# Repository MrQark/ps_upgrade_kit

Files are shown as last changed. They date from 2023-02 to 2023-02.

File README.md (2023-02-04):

# Power Supply Upgrade Kit

Power Supply Upgrade Kit (PSUK) allows to turn a power supply into LiFePO4 charger

# Objectives

To convert the existing power supply [ATABA S-360-12](https://prom.ua/ua/p1276775685-impulsnyj-blok-pitaniya.html) into LiFePO4 battery charger.

# Requirements

1. Current regulation.

REQ-001. PSUK shall linearly regulate output current up to the Threshold Value.

REQ-002. Current regulation Threshold Value selection shall be done by the variable resistor in the range from 5A to 25A (wider range is also acceptable).

REQ-003. Switching to current regulation shall be indicated by the yellow LED.

REQ-004. Current regulation shall not decrease output voltage lower than 10V to preserve the Fan operation in the current regulation mode.

2. Battery isolation.

REQ-005. If no AC power available the PSUK output shall be electically disconnected from the battery to avoid battery disharge by the fan and voltage feedback stages.

3. Voltage regulation.

REQ-006. PSUK shall extend the output voltage adjustment range up to 15V. Note: in the original state it is limited to 14-14.1V.

4. Fan control.

REQ-007. PSUK shall not activate the cooling FAN if the output current is near zero (0-0.3A) otherwise the FAN shall be operating.

Note: this requirement is for supporting the UPS use case when the soundless operation is preferred.

# Concept

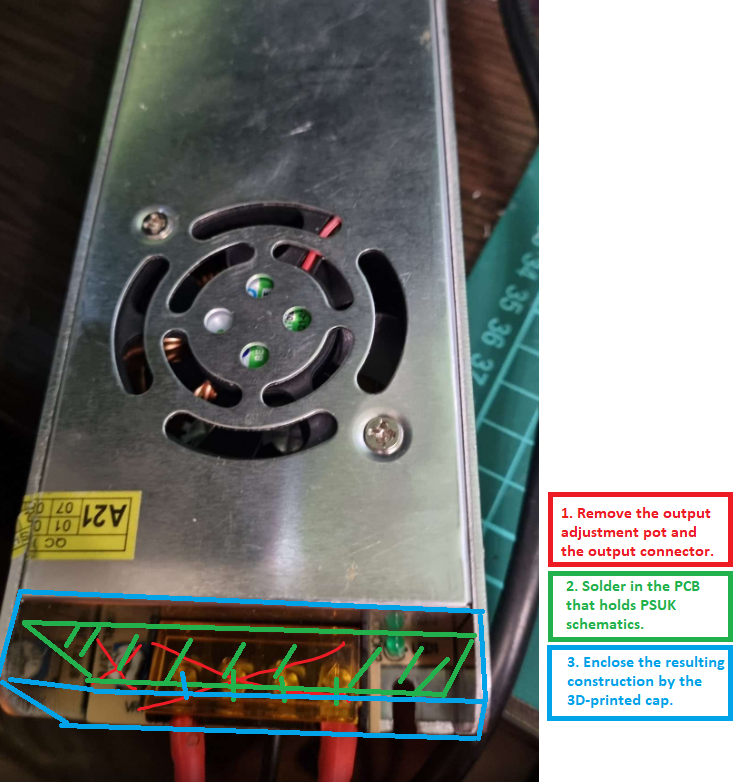
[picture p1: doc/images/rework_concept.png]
PSUK concept


# Power Supply data

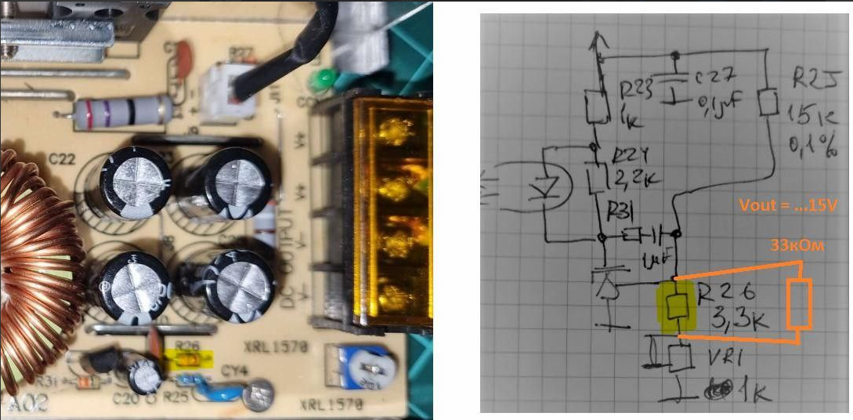
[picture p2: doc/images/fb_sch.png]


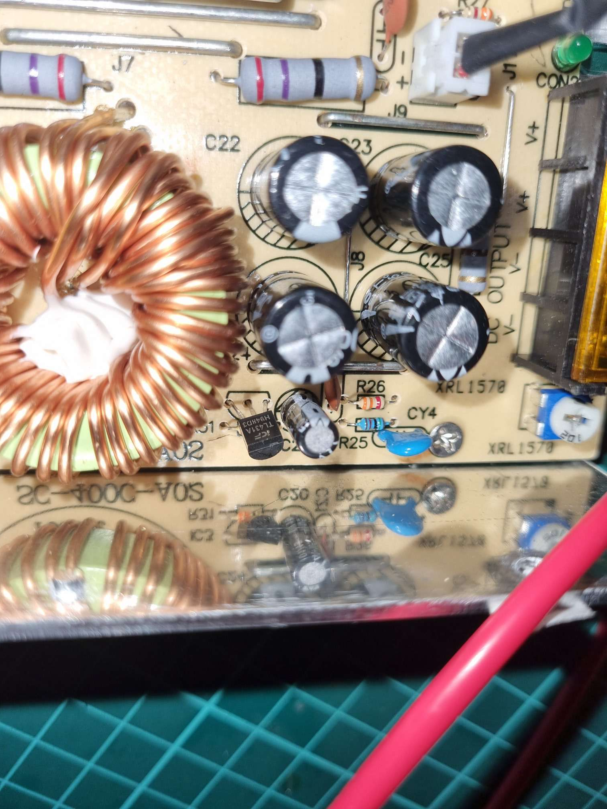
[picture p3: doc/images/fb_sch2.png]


# References

https://danyk.cz/reverz44_en.html

https://elektrotanya.com/s-360-12_12v_30a_power_supply_sch.pdf/download.html

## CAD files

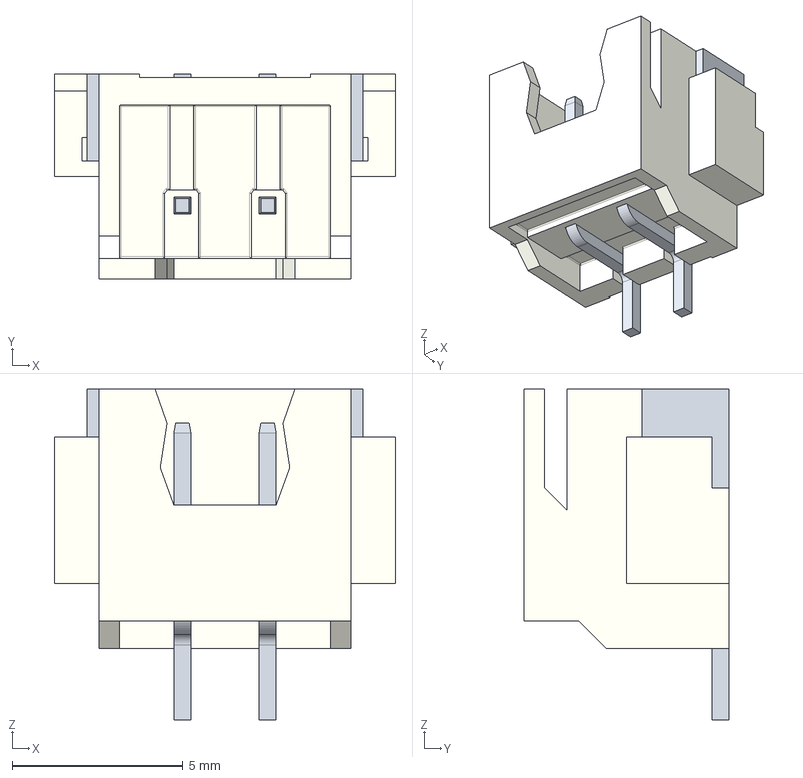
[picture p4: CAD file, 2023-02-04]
kicad_prj/psuk_lib/3d models/xh_2_54_fixed_terminal_asm.stp
10.0 x 6.00 x 9.70 mm
HOUSE
PIN x 2
FEET x 2

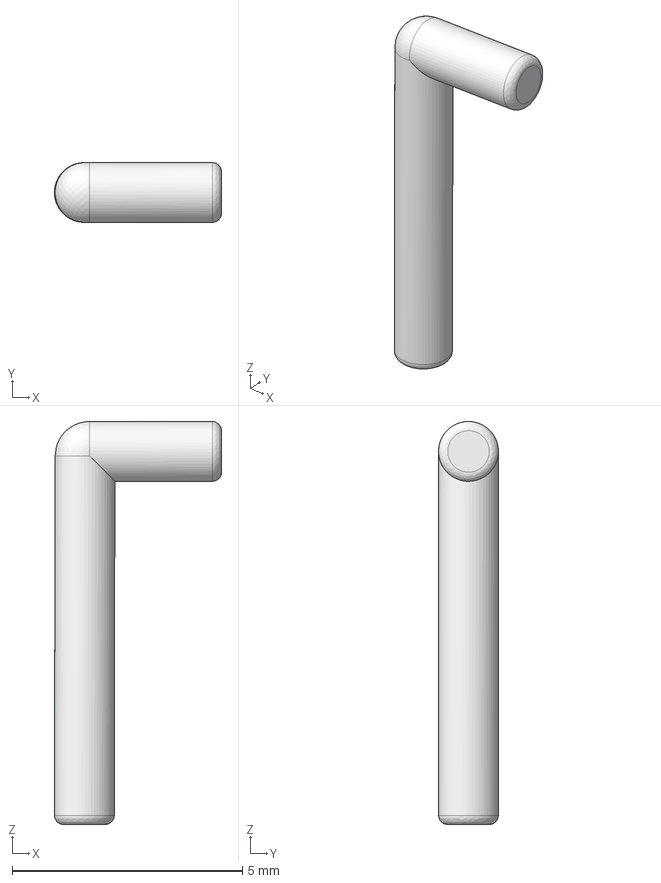
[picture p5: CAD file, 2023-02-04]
kicad_prj/psuk_lib/3d models/psuk_connector.FCStd
3.63 x 1.30 x 8.75 mm

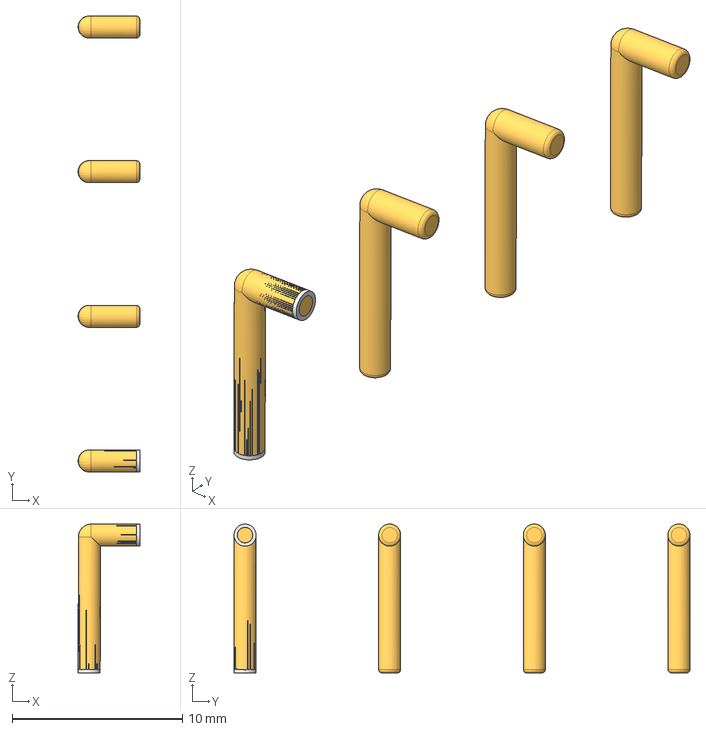
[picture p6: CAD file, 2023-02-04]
kicad_prj/psuk_lib/3d models/psuk_connector-Part.step
3.63 x 26.8 x 8.75 mm
AdditivePipe

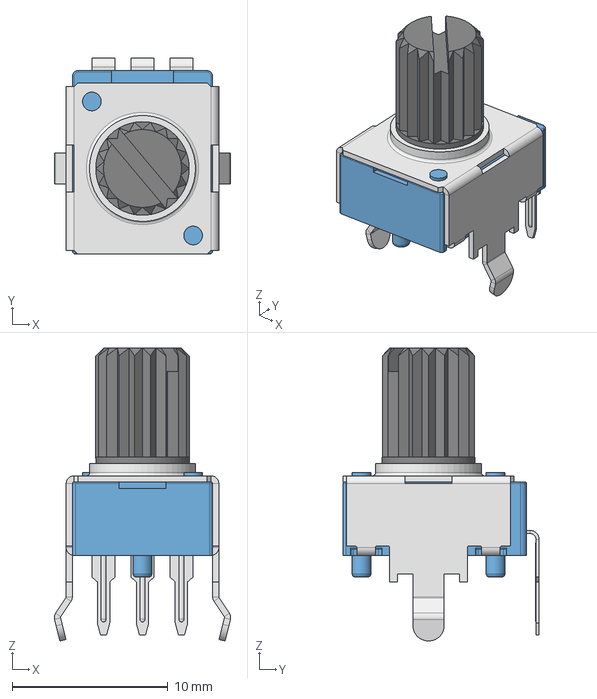
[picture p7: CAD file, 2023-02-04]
kicad_prj/psuk_lib/3d models/R-0904N-L-15KC.step
11.3 x 12.6 x 18.8 mm

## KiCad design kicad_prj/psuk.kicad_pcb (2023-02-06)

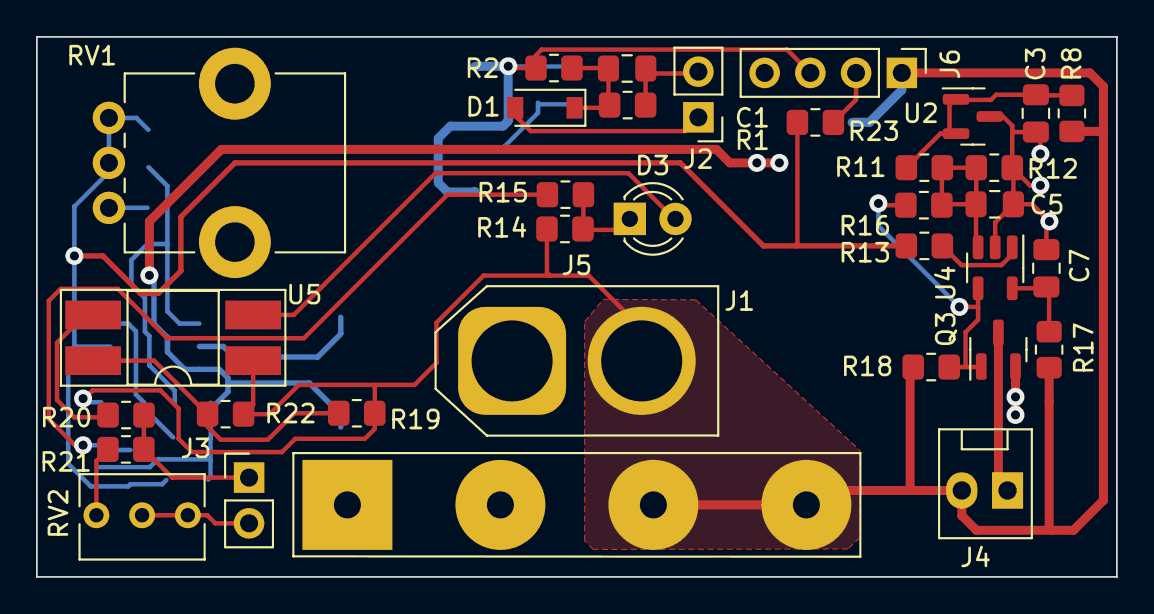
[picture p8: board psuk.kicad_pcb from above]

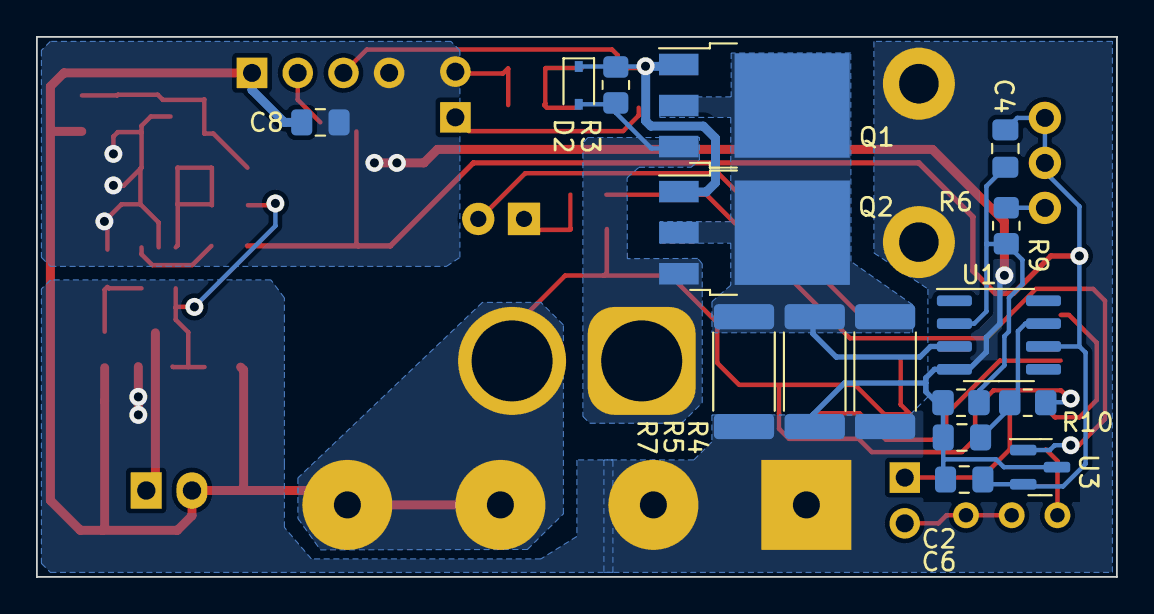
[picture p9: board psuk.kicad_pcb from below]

Board: 2 copper layers, 60.0 x 30.0 mm, 50 parts (16 on the bottom side), 26 nets.

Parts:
C1: 10u/25V; C_0805_2012Metric_Pad1.18x1.45mm_HandSolder
C2, C3, C5, C7, C8: 100n; C_0805_2012Metric_Pad1.18x1.45mm_HandSolder
C4: 150pF; C_0805_2012Metric_Pad1.18x1.45mm_HandSolder
C6: 1n; C_0805_2012Metric_Pad1.18x1.45mm_HandSolder
D1: 1N4148W; D_SOD-123
D2: BZX384B10; D_SOD-323
D3: YEL-3mm; LED_D3.0mm
J1: ATABA S-360-12 connector
J2, J3: 22-23-2021; PinHeader_1x02_P2.54mm_Vertical
J4: XH2.54-2P; FanPinHeader_1x02_P2.54mm_Vertical
J5: XT-60F; AMASS_XT60-F_1x02_P7.20mm_Vertical
J6: Conn_01x04_Male; PinHeader_1x04_P2.54mm_Vertical
Q1, Q2: AOD240; TO-252-3_TabPin2
Q3: IRLML2502TRPBF; SOT-23
R1, R3, R18: 15k; R_0805_2012Metric_Pad1.20x1.40mm_HandSolder
R2, R8, R12, R15: 2k2; R_0805_2012Metric_Pad1.20x1.40mm_HandSolder
R4, R5, R7: R003; R_2512_6332Metric_Pad1.40x3.35mm_HandSolder
R6, R10, R13, R17, R23: 47; R_0805_2012Metric_Pad1.20x1.40mm_HandSolder
R9: 4k3; R_0805_2012Metric_Pad1.20x1.40mm_HandSolder
R11, R19, R20: 30k; R_0805_2012Metric_Pad1.20x1.40mm_HandSolder
R14: 1k; R_0805_2012Metric_Pad1.20x1.40mm_HandSolder
R16: 1M; R_0805_2012Metric_Pad1.20x1.40mm_HandSolder
R21: 3k; R_0805_2012Metric_Pad1.20x1.40mm_HandSolder
R22: DNM; R_0805_2012Metric_Pad1.20x1.40mm_HandSolder
RV1: 10k; Potentiometer_Bourns_PTV09A-1_Single_Vertical
RV2: 1k; Potentiometer_Bourns_3266Y_Vertical
U1: OPA189IDR; SOIC-8_3.9x4.9mm_P1.27mm
U2, U3: TL431DBZ; SOT-23
U4: LM397; SOT-23-5
U5: FOD817B3SD; DIP-4_W8.89mm_SMDSocket_LongPads

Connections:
+12V: C8.2, J1.3 (+), J1.4 (+), J4.2, J5.2, J6.1, R8.1, R10.2, R14.1, R17.2, R18.2, R19.1, R22.1, U5.1
GND: C1.1, C2.1, C3.1, C5.1, C6.1, C7.1, C8.1, J1.1 (-), J1.2 (-), J2.2, J6.4, Q3.2 (S), R1.2, R4.2, R5.2, R6.1, R7.2, R12.2, RV1.MP (MountPin), U1.4 (V-), U2.3 (A), U3.3 (A), U4.2 (V-)
unnamed: C1.2, D1.1 (K), R1.1, R2.1
unnamed: C2.2, R10.1, U1.7 (V+)
unnamed: C3.2, R8.2, R11.1, U2.1 (K), U2.2 (REF)
unnamed: C4.1, C6.2, R13.1, R23.1, RV1.2, RV1.3, U1.6, U3.2 (REF)
unnamed: C4.2, R6.2, R9.1, U1.2 (-)
unnamed: C5.2, R11.2, R12.1, R16.1, U4.3 (+)
unnamed: C7.2, R17.1, U4.5 (V+)
unnamed: D1.2 (A), J2.1
unnamed: D2.1 (K), J6.3, Q1.1 (G), Q2.1 (G), R2.2, R3.1
unnamed: D2.2 (A), J5.1, Q1.3 (S), Q2.3 (S), R3.2
unnamed: D3.1 (K), R14.2, R15.1
unnamed: D3.2 (A), U5.2
unnamed: J3.1, R20.2, R21.1
unnamed: J3.2, RV2.1, RV2.2
unnamed: J4.1, Q3.3 (D)
unnamed: J6.2, R23.2
unnamed: Q1.2 (D), Q2.2 (D), R4.1, R5.1, R7.1, U1.3 (+)
unnamed: Q3.1 (G), R16.2, R18.1, U4.4
unnamed: R9.2, RV1.1
unnamed: R13.2, U4.1 (-)
unnamed: R15.2, U3.1 (K)
unnamed: R19.2, R22.2, U5.4
unnamed: R20.1, U5.3
unnamed: R21.2, RV2.3

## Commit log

2023-02-03 Updated the PSUK schematics.
    [psuk.kicad_pcb]
2023-02-04 Updated schematics. Fixed wrong and missing 3D models.
    [R-0904N-L-15KC.step, psuk.kicad_pcb, psuk_connector-Part.step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]
2023-02-04 Added unsaved changes in schematics.
2023-02-06 Completed PCB routing. Released v1.0 artifact for production and procurement purposes.
    [psuk.kicad_pcb]
